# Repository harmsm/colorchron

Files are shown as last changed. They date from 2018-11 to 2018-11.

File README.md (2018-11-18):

# Colorchron

#### A physical clock that represents the current time using LED color

This project uses a raspberry pi to show the time using the color value of a
collection of LEDs.  This was inspired by work such as 
[what color is it?](http://whatcolorisit.sumbioun.com/), 
the [colour clock](http://thecolourclock.co.uk/), and the famous
[chromachron watch](https://www.hodinkee.com/articles/chromachron-a-radically-new-approach-to-time).

Using the default configuration, the clock will start at 
blue and then sweep around the RGB colorwheel counterclockwise over 24 hours.  

|  time | color |
|---|---|
|  0:00 | blue |
|  4:00 | cyan |
|  8:00 | green |  
| 12:00 | yellow  |
| 16:00 | red |
| 20:00 | magenta |

The clock can also incorporate an ambient light sensor that tunes the brightness
of the clock so it is brighter in daylight and dimmer at night.

### Basic example script
```python
import colorchron

clock = colorchron.Clock()
colorwheel = colorchron.colorwheel.RGB()
led = colorchron.led.Neopixel()
light_sensor = colorchron.light_sensor.CJMCU3216()

clock.add_colorwheel(colorwheel)
clock.add_ambient_light_sensor(light_sensor)
clock.add_led(led)

clock.start()
```

+ The ambient light sensor and LEDs are optional.  (Of course, if you don't load
  the LEDs, the program won't do anything particularly interesting).
+ To see what options you have for tweaking the clock output, run `python3` on
  the command line.  Then run the following:

  ```python
  import colorchron
  help(colorchron.Clock)
  ```

## Installation

### Set up the pi

You will need a raspberry pi running a (relatively) recent operating system that
has python3 available in the package manager.  The instructions below are known
to work work for raspbian stretch light (kernel 4.14).  

The clock uses the system time to determine its color.  If you want the time to
be set automatically, you need to configure the pi to be on the internet while
the clock is running.  If you want to set the date manually, run:

```
sudo date -s '2018-11-14 11:26:00'
```

### Activate I2C 

1. At the command line, run `sudo raspi-config`
2. Select `P5 I2C` and hit `Enter.`  
3. Reboot the pi.

### Install git and smbus

1. At the command line, run `sudo apt-get install git python3-smbus`
2. Answer `Y` to any prompts.

### Install colorchron clock

1. Clone the `colorchron` git repository.  At the command line, run
   `git clone https://github.com/harmsm/colorchron.git`
2. Install the colorchron clock.  Run `cd colorchron` followed by
   `sudo python3 setup.py install` 

### Running the clock
1. At the command line, navigate into the `colorchron/example` directory.  This 
   directory has a script called `run_clock.py`.  
2. Run `sudo python3 run_clock.py`.  If the hardware is configured correctly,
   the clock should start running.

### To start the clock on boot
1. In the `colorchron/example` directory, run the command `pwd`.  This should 
   print out the path (something like `/home/hermione/colorchron/example`). 
   Select and copy the path. 
2. Open the `/etc/rc.local` file in an editor (`nano /etc/rc.local`).  
3. Somewhere before the line reading `exit 0` put the line:

   ```
   python3 /home/hermione/colorchron/example/run_clock.py &
   ```

   replacing the path with the one you copied above.  **The `&` is critical.  
   If you do not include it, the pi will not boot!**
4. Save the file and reboot the pi.  The clock LEDs should light up as soon 
   as the pi finishes booting, even if you do not log in.

## Hardware

[fritzing](http://fritzing.org) design files and pictures are of the
build available in the `design/` directory.

### Parts list

+ Raspberry pi with necessary accessories (power supply, SD card, header pins,
  case)
+ 74AHCT125 logic-level converter OR 1N4001 diode to allow 3.3V logic on pi to
  interface with 5V logic on LED array diode. 
  [See here](https://learn.adafruit.com/neopixels-on-raspberry-pi/raspberry-pi-wiring).
+ String of WS2812 LEDs.
+ MJMCU 3216 ambient light sensor.  (If you use a different light sensor, it
  must connect via SDA/SCL.  You may have to change the addresses in the file
  `colorchron/light_sensor/cjmcu3216.py`.  If you end up writing a driver for a 
  different light sensor, feel free to make a pull request for this project). 
+ Appropriate wires. 

### Design

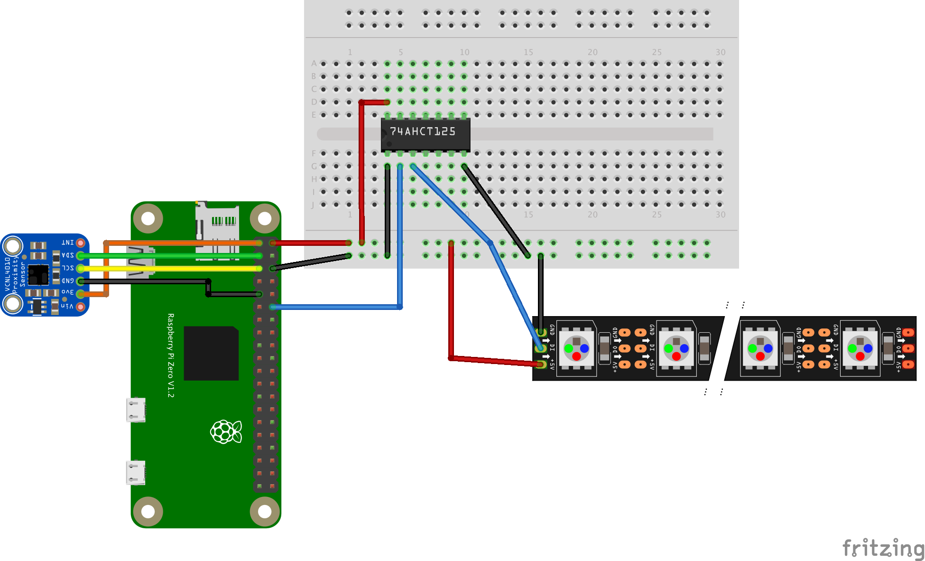
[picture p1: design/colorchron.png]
design here


+ In the diagram, I used a proximity sensor with similar pins instead of an 
  MJMCU3216 to avoid making a special fritzing part just for this picture. 
+ The light sensor is powered by 3.3 V pin and connects via SDA/SCL pins
+ The LED array is powered by a 5 V pin and connects via the D18 pin.  

**NOTE.  This design powers the LED array off of the 5V pin on the raspberry 
pi.  This works for <= 15 LEDs before exceeding the current available on that
pin.  It also assumes you are not powering other peripherals (with the 
exception of the ambient light sensor).  If you want to have more LEDs, use
an external 5V power supply.  [See here](https://learn.adafruit.com/neopixels-on-raspberry-pi/raspberry-pi-wiring).**

### Implementation

+ I ended up soldering the 74AHCT125 logic level converter into a prototype
  board to avoid a huge number of jumper wires. 

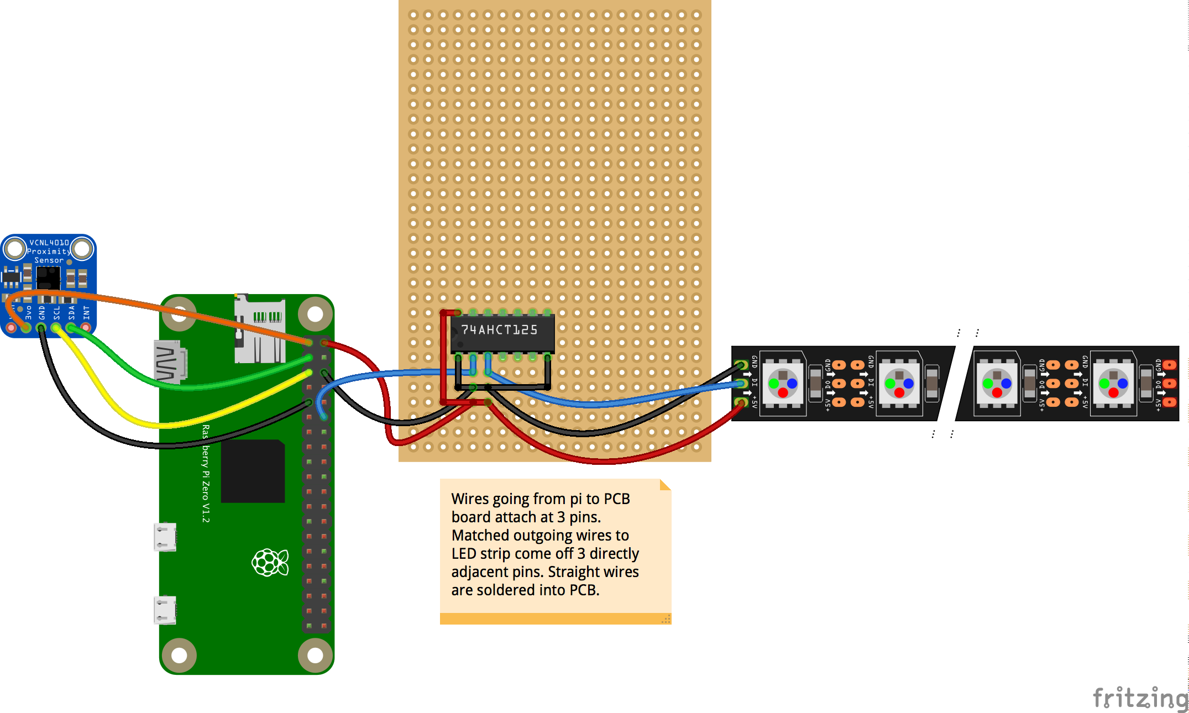
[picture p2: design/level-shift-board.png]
logic level


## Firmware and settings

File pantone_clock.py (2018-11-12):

#!/usr/bin/env python3
__description__ = \
"""
Control a pantone clock that displays an RGB value to represent time.  
Using the default configuration, the clock will start at blue and then
sweep around the RGB colorwheel counterclockwise over 24 hours.  

 0:00 blue
 4:00 cyan
 8:00 green
12:00 yellow
16:00 red
20:00 magenta

The clock can also incorporate an optional ambient light sensor that dims
the clock in the dark.

If run as a standalone program, the library takes a json file containing
the keyword arguments passed to PantoneClock.__init__.  The special 
key "ambient" in that json file should contain a dictionary of keyword
arguments for AmbientLightSensor.__init__, if an ambient light sensor
is to be used with the clock.

If run as a library, a clock instance can be created, started, and 
stopped.  The clock runs on its own thread, so other processes may
run after it spawns.

import pantone_clock
p = pantone_clock.PantoneClock([pin1,pin2,pin3])
p.start()
"""
__usage__ = "pantone_clock.py json_config_file"
__author__ = "Michael J. Harms"
__date__ = "2018-04-30"

#from RPi import GPIO
import time, datetime, json, sys, copy, multiprocessing

#GPIO.setmode(GPIO.BCM)

class AmbientLightSensor:
    """
    Read an ambient light sensor and return a value between min_out and
    max_out.
    """

    def __init__(self,
                 sensor_pin,
                 min_out=0.05,max_out=1.0,
                 min_meas=0,max_meas=255):
        """
        sensor_pin: GPIO pin to read (BCM numbering)
        min_out: lowest value that will ever be put out by class 
        max_out: highest value that will ever be put out by class 
        min_meas: measurement value corresponding to min_out
        max_meas: measurement value corresponding to max_out
        """

        self._sensor_pin = sensor_pin
        self._min_out = min_out
        self._max_out = max_out
        self._min_meas = min_meas
        self._max_meas = max_meas

        # Define linear relationship between measurement and output values
        self._slope = (self._max_out - self._min_out)/(self._max_meas - self._min_meas)
        self._intercept = self._max_out - self._slope*self._max_meas

        # Set up pin
        #GPIO.setup(self._sensor_pin,GPIO.IN)
  
    @property
    def brightness(self):
        """
        Return the brightness.
        """

        #value = GPIO.input(self._sensor_pin)
        value = 255

        if value < self._min_meas:
            return self._min_out

        if value > self._max_meas:
            return self._max_out

        return self._intercept + self._slope*value
          

class PantoneClock:
    """
    Control a pantone clock attached to three GPIO pins.
    """
    
    def __init__(self,
                 pin_numbers,
                 seconds_per_cycle=86400,
                 pantone_zero_position=240,
                 counterclockwise=True,
                 update_interval=0.1,
                 brightness=1.0,
                 min_brightness=0.05):
        """
        pin_numbers: list or tuple of 3 GPIO pins (BCM numbering)
        seconds_per_cycle: number of seconds that it takes to sweep the entire
                           RGB wheel.  86400 s corresponds to 24 hr
        pantone_zero_position: wheel position, in degrees, corresponding to 0
                               seconds.  This is midnight for the default 24 
                               hour clock.  0: red, 60: yellow, 120: green,
                               180: cyan, 240: blue, 300: magenta.  
        counterclockwise: go counterclockwise around the RGB wheel
        update_interval: how often to update the clock in seconds.
        brightness: overall brightness of the clock (between 0 and 1).  If an 
                    ambient light sensor is used, the brightness scalar will
                    be applied on top of brightness changes indicated by the
                    sensor.
        min_brightness: minimum brightness of clock
        """

        # Argument sanity checks
        self._pin_numbers = pin_numbers[:]
        if len(self._pin_numbers) != 3:
            err = "clock requires three GPIO pins.\n"
            raise ValueError(err)
        
        self._sec_per_cycle = seconds_per_cycle
        if self._sec_per_cycle <= 0:
            err = "seconds_per_cycle must be greater than zero.\n"
            raise ValueError(err)

        self._pantone_zero_position = pantone_zero_position
        self._counterclockwise = bool(counterclockwise)

        self._update_interval = update_interval
        if self._update_interval <= 0:
            err = "update interval must be greater than zero.\n"
            raise ValueError(err)

        self._brightness = brightness
        if self._brightness < 0 or self._brightness > 1:
            err = "brightness must be between 0 and 1.\n"
            raise ValueError(err)

        self._min_brightness = min_brightness
        if self._min_brightness < 0 or self._min_brightness > 1:
            err = "minimum brightness must be between 0 and 1.\n"
            raise ValueError(err)

        # Configure GPIO pins
        self._pins = []
        #for pin in self._pin_numbers:
            #GPIO.setup(pin,GPIO.OUT)
            #self._pins.append(GPIO.PWM(pin,50))
            #self._pins[-1].start(50)

        # Put starting position in terms of a fraction of the total
        # sweep 
        fx_pantone_zero = self._pantone_zero_position % 360
        fx_pantone_zero = fx_pantone_zero/360.0

        # Configure each channel
        self._rgb = [0.,0.,0.]
        self._channel_offsets = []
        for i in range(3):
            v = fx_pantone_zero + i*self._sec_per_cycle/3
            self._channel_offsets.append(v)

        # Configure intervals for cycling the clock
        self._intervals = [1/6.,3/6.,4/6.]

        # Currently no light sensor
        self._light_sensor = None

        # Currently stopped
        self._running = False

    def _calc_rgb_values(self,time):
        """
        Calculate the RGB channel values corresponding to this time.
        """

        for i in range(3):

            # Figure out how far around the clock we should be
            channel_time = time + self._channel_offsets[i]
            fx_time = (channel_time % self._sec_per_cycle)/self._sec_per_cycle

            # Run counter clockwise if requested
            if self._counterclockwise:
                fx_time = 1 - fx_time
        
            # Ramp between 0 and 1 for the 1st sixth of the clock
            if fx_time < self._intervals[0]:
                self._rgb[i] = fx_time/self._intervals[0]
                continue

            # Hold at 1 for the 2nd and 3rd sixth of the clock
            if fx_time >= self._intervals[0] and fx_time < self._intervals[1]:
                self._rgb[i] = 1.0
                continue

            # Ramp between 1 and 0 for the 4th sixth of the clock 
            if fx_time >= self._intervals[1] and fx_time < self._intervals[2]:
                m = 1/(self._intervals[1] - self._intervals[2]) 
                b = 1 - self._intervals[1]*m 
                self._rgb[i] = fx_time*m + b
                continue
       
            # Hold at 0 for the 5th and 6th sixth of the clock
            self._rgb[i] = 0.0

    def _update(self):
        """
        Update the clock.
        """  

        # Get the current time.
        now = datetime.datetime.now()

        # Convert into seconds since midnight
        time_in_seconds = (now.hour*60 + now.minute)*60 + now.second

        # Update the RGB values with this new time 
        self._calc_rgb_values(time_in_seconds)

        # Set the brightness, imposing limit that forces value to be between
        # 1 and the minimum brightness. 
        bright_scalar = self.brightness*self.ambient_brightness
        if bright_scalar > 1:
            bright_scalar = 1.0
        if bright_scalar < self._min_brightness:
            bright_scalar = self._min_brightness

        # Normalize channels so total duty cycle is always 100*bright_scalar.
        # This keeps the intensity the same, whether light is coming from
        # one or two output channels
        total = sum(self.rgb)
        for i in range(3):
            value = bright_scalar*100*self.rgb[i]/total
            print(value,end=" ")
        #    self._pins[i].ChangeDutyCycle(value)
        print("")

    def _run(self):
        """
        Loop that updates clock every update_interval seconds.
        """    

        while True:
            self._update()
            time.sleep(self._update_interval)
 

    def start(self):
        """
        Start the clock on its own thread.
        """

        # If already running, do not start
        if self._running:
            return

        self._process = multiprocessing.Process(target=self._run)
        self._process.start()
        self._running = True
 
    def stop(self):
        """
        Stop the clock.
        """           

        # Do not running, do not stop
        if not self._running:
            return

        self._process.terminate()
        self._running = False

    def add_ambient_light_sensor(self,light_sensor):
        """
        Add an ambient light sensor.
        """

        self._light_sensor = light_sensor
        try:
            self._light_sensor.brightness
        except AttributeError:
            err = "Light sensor not readable.  Must have 'brightness' attribute.\n"
            raise ValueError(err)

    @property
    def brightness(self):
        """
        Brightness (controlled by user).  Read, but NOT set by thread.  This
        means the brightness can be adjusted while the clock is running.
        """       
 
        return self._brightness

    @brightness.setter
    def brightness(self,brightness):
        """
        Set the brightness.
        """

        if brightness < 0 or brightness > 1:
            err = "Brightness must be between zero and 1.\n"
            raise ValueError(err)

        self._brightness = float(brightness)

        # Make the thread come up for air and grab the new brightness value
        if self._running:
            self.stop()
            self.start()

    @property
    def rgb(self): return self._rgb

    @property
    def ambient_brightness(self):
        """
        Ambient brightness.  If no sensor has been added, return 1.0.  
        """
        
        if self._light_sensor is None:
            return 1.0
        else:
            return self._light_sensor.brightness
                

def main(argv=None):

    if argv is None:
        argv = sys.argv[1:]

    # Parse command line
    try:
        control_file = argv[0]
    except IndexError:
        err = "Incorrect arguments. Usage:\n\n{}\n\n".format(__usage__)
        raise ValueError(err)

    # load in json file
    data = json.loads(open(control_file,'r').read())

    # Parse configuration file.  Keys should be keyword arguments to 
    # PantoneClock.__init__.  The key "ambient" is a special key that should
    # point to a dictionary of keywords to be passed to 
    # AmbientLightSensor.__init__.
    ambient_kwargs = {}
    pantone_kwargs = {}
    for k in data.keys():
        if k == "ambient":
            ambient_kwargs = copy.deepcopy(data[k])
        else:
            pantone_kwargs[k] = copy.deepcopy(data[k])

    # Create clock 
    clock = PantoneClock(**pantone_kwargs) 
    
    # Potentially create an ambient light sensor
    if len(ambient_kwargs) > 0:
        light_sensor = AmbientLightSensor(**ambient_kwargs)
        clock.add_ambient_light_sensor(light_sensor)
   
    # Start the clock 
    clock.start() 
  

if __name__ == "__main__":
    main()

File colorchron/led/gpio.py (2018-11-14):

#!/usr/bin/env python3
__description__ = \
"""
Driver for GPIO LED array.
"""
__author__ = "Michael J. Harms"
__date__ = "2018-11-12"

from .base import LED

from RPi import GPIO
GPIO.setmode(GPIO.BCM)

class GPIO(LED):

    def __init__(self,pin_numbers):

        self._pin_numbers = pin_numbers[:]
        if len(self._pin_numbers) != 3:
            err = "GPIO LEDs require three GPIO pins.\n"
            raise ValueError(err)

        # Configure GPIO pins
        self._pins = []
        for pin in self._pin_numbers:
            GPIO.setup(pin,GPIO.OUT)
            self._pins.append(GPIO.PWM(pin,50))
            self._pins[-1].start(50)


    def set(self,rgb):

        for i in range(3):

            freq = 100*value/255
            self._pins[i].ChangeDutyCycle(freq)

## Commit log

2018-11-13 clock now assembled and working
2018-11-14 added design files
    [pantone-clock.fzz]
2018-11-14 added design for soldered level-shift board
    [level-shift-board.fzz]
2018-11-14 updating docs
    [level-shift-board.fzz]
2018-11-18 fixed error in diagram
    [level-shift-board.fzz, pantone-clock.fzz]
2018-11-18 some mods
    [colorchron.fzz]
2018-11-18 changed default wheel
